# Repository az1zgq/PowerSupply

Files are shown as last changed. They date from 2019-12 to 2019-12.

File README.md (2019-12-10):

### Блок питания
Данный блок питания преобразует ~220В в 5В
#### Стукрура проекта
- [AD Libraries](AD%20Libraries)
    - [PCB Library Documents](AD%20Libraries/PCB%20Library%20Documents)
    - [Schematic Library Documents](AD%20Libraries/Schematic%20Library%20Documents)
- [Simulink](Simulink)
    - PowerSupply.ms14
- [Template](Template)
    - GOST 26.008-85.TTF
    - GOST 85.TTF
    - GOST type A.ttf
    - GOST type B.ttf
    - isocpeur-italic.ttf
    - isocpeur.ttf
- [pcbDrawing](pcbDrawing)
    - pcbDrawing.dwg
    - [pdfDrawing](pcbDrawing/pdfDrawing)
        - [ИУ4.11.03.03.19.05.02.04.001 Э1](pcbDrawing/pdfDrawing/%D0%98%D0%A34.11.03.03.19.05.02.04.001%20%D0%AD1.pdf)
        - [ИУ4.11.03.03.19.05.02.04.003 Э3](pcbDrawing/pdfDrawing/%D0%98%D0%A34.11.03.03.19.05.02.04.003%20%D0%AD3.pdf)
        - [ИУ4.11.03.03.19.05.02.04.003 ПЭ3](pcbDrawing/pdfDrawing/%D0%98%D0%A34.11.03.03.19.05.02.04.003%20%D0%9F%D0%AD3.pdf)
        - [ИУ4.11.03.03.19.05.02.04.004 ПП](pcbDrawing/pdfDrawing/%D0%98%D0%A34.11.03.03.19.05.02.04.004.pdf)
        - [ИУ4.11.03.03.19.05.02.04.005 СБ](pcbDrawing/pdfDrawing/%D0%98%D0%A34.11.03.03.19.05.02.04.005%20%D0%A1%D0%91.pdf)
        - [ИУ4.11.03.03.19.05.02.04.006 Э1с ](pcbDrawing/pdfDrawing/%D0%98%D0%A34.11.03.03.19.05.02.04.006.pdf)
        - [ИУ4.11.03.03.19.05.02.04.008 СП](pcbDrawing/pdfDrawing/%D0%98%D0%A34.11.03.03.19.05.02.04.008%20%D0%A1%D0%9F.pdf)
        - [experiment](pcbDrawing/pdfDrawing/experiment.pdf)
        - [RPZ](pcbDrawing/pdfDrawing/RPZ.pdf)

- [pcbBoard](pcbBoard)
    - powerSupply.PrjPcb
    - Schematic.SchDoc
    - pcbBoard.PcbDoc
    - pdf.OutJob
    - gerber.OutJob
    - [Корзина](pcbBoard/Корзина.pdf)

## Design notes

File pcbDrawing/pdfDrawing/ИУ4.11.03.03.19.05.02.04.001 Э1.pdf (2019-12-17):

Сетевое нааряжение 220 В 50 Гц | Выход 5 В Защита от короткого замыкания | Выпрямитель с фильтром | Силовые ключи | Импульсный трансформатор | Выходной выпрямитель на диоде шоттки | Блок индикации Схема стабилизации . Гальваническая развязка обратной связи по напряжению на оптроне | Разраб . Пров . Изм . Лист | № докум . | Подпись | Дата | Лит . | Масса | Масштаб Т .контр . | Лист | Листов 1 Реценз . Н .контр . Утв . | МГТУ им . Н .Э .Баумана Кафедра ИУ 4 Группа ИУ 4-52 Б Блок питания Схема электрическая структурная Исмаилов А .К . Сергеева М .Д . Семенцов С .Г . 1 Э | 4.11.03.03.19.05.04.001 | ИУ

Инв . № подл Подп . и Дата Взам .инв .№ Инв .№ дубл . Подп . и Дата Справ № Перв . примен . ИУ 4.11.03.03.19.02.04.001 Э 1 ИУ 4.11.03.03.19.05.02.04.001 Э 1 Схема управление ключом Копировал Формат А 3

ВЫПОЛНЕНО В СТУДЕНЧЕСКОЙ ВЕРСИИ ПРОГРАММЫ AUTODESK ВЫПОЛНЕНО В СТУДЕНЧЕСКОЙ ВЕРСИИ ПРОГРАММЫ AUTODESK

ВЫПОЛНЕНО В СТУДЕНЧЕСКОЙ ВЕРСИИ ПРОГРАММЫ AUTODESK ВЫПОЛНЕНО В СТУДЕНЧЕСКОЙ ВЕРСИИ ПРОГРАММЫ AUTODESK

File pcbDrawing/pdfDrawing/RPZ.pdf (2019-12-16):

Министерство науки и высшего образования Российской Федерации Федеральное государственное бюджетное образовательное учреждение высшего образования
«Московский государственный технический университет имени Н.Э. Баумана (национальный исследовательский университет МГТУ им. Н.Э. Баумана) »

ФАКУЛЬТЕТ Информатика и системы управления (ИУ)

КАФЕДРА Проектирование и технология производства электронной аппаратуры (ИУ4)

## РАСЧЕТНО-ПОЯСНИТЕЛЬНАЯ ЗАПИСКА

## К КУРСОВОЙ РАБОТЕ

## НА ТЕМУ: Разработка, моделирование и экспериментальное исследование Блока питания

Студент ___ИУ4-52____ | _______________________ Исмаилов А.К
(Группа) | (Подпись, дата)
Проверил: | _______________________ Сергеева М.Д
| (Подпись, дата)
Руководитель курсовой работы | _______________________ Семенцов С.Г
| (Подпись, дата)

2019 г.

АННОТАЦИЯ
Работа посвящена разработке Блока питания (в дальнейшем — изделия). В работе представлена схемотехническая часть, содержащая информацию об элементной базе и описание электрической принципиальной схемы. Работа представляет собой комплекс графических документов. Содержание графической части: схема электрическая принципиальная, чертеж печатной платы, сборочный чертеж, спецификации. В заключении представлены выводы о проделанной работе и соответствии разработанного устройства техническому заданию.
Ключевые слова: Блок питания, схемотехническое проектирование.

ABSTRACT

The work is devoted to the development of a power supply unit (hereinafter referred to as products).
The work presents the circuit parts in which there is information about the elementary base and a description of the electrical circuit diagrams. The work is a set of graphic documents. The contents of the graphic part: electrical schematic diagram, assembly diagram, specification. In conclusion, conclusions are presented about the work done and the compliance with the terms of reference developed by the device. Key words: power supply, circuit design.

СОДЕРЖАНИЕ

УСЛОВНЫЕ ОБОЗНАЧЕНИЯ, СОКРАЩЕНИЯ И ТЕРМИНЫ
1 СХЕМОТЕХНИЧЕСКОЕ ПРОЕКТИРОВАНИЕ ИЗДЕЛИЯ | 8
1.2 Анализ и разработка схемы электрической принципиальной (Э3) изделия | 9
Основные характеристики BD106 | 11
Транзистор ST13003 служит для усиления электрического тока и управления им | 11
Основные характеристики ST13003 | 11
Вывод: данный транзистор был выбран в виду своей доступности и простоты
использования | 11
Транзистор BD135 способен от небольшого входного сигнала управлять значительным
током в выходной цепи | 12
Основные характеристики BD135 | 12
Макс. напр. к-б при заданном обратном токе к и разомкнутой цепи эмиттера 45В | 12
Вывод: данный транзистор был выбран так как его описание подходит требованиям
технического задания | 12
Оптопара PC817B обеспечивает гальваническую развязку вторичных цепей блока
питания от напряжения сети | 12
Основные характеристики PC817B | 12
Вывод: данный элемент был выбран так как его характеристики удовлетворяют
требованиям технического задания | 12
Выводы | 13
2 КОНСТРУКТОРСКОЕ ПРОЕКТИРОВАНИЕ ИЗДЕЛИЯ | 14
2.1 Анализ и выбор конструкции и материала печатной платы изделия | 14
2.2 Анализ соединений КМО электронного модуля | 15
Выводы | 16
3 Моделирование устройства | 17
3.1 Компьютерное моделирование работы изделия | 17
ЗАКЛЮЧЕНИЕ | 22
СПИСОК ИСПОЛЬЗОВАННЫХ ИСТОЧНИКОВ | 23
1 СХЕМОТЕХНИЧЕСКОЕ ПРОЕКТИРОВАНИЕ ИЗДЕЛИЯ | 7
1.1 Анализ и разработка схемы электрической структурной (Э1) изделия | 7
1.2 Анализ и разработка схемы электрической принципиальной (Э3) изделия | 8

УСЛОВНЫЕ ОБОЗНАЧЕНИЯ, СОКРАЩЕНИЯ И ТЕРМИНЫ

ГОСТ | – Государственный стандарт;
ЕСКД | – Единая система конструкторской документации;
КМО | – Компонент монтируемый в отверстие;
ПП | – Печатная плата;
СТФ | – Стеклотекстолит фольгированный;
РПЗ | – Расчётно-пояснительная записка;
РТЗ | – Расширенное техническое задание;
РЭС | –Радиоэлектронные средства;
РЭА | – Радиоэлектронные аппаратура;
ТЗ | – Техническое задание;
ТЭЗ | – Типовой элемент замены;
ЭРЭ | – Электрорадиоэлементы;

ВВЕДЕНИЕ

Работа посвящена разработке Блока питания, изготовлению и экспериментальному исследованию
В работе представлена схемотехническая часть, содержащая информацию об элементной базе и описание электрической принципиальной схемы. Работа представляет собой комплекс графических документов
Целью работы является разработка макетного образца изделия, которое преобразует из сетевого переменного напряжения в постоянное, и проектирование сопровождаещего комплекта конструкторской документации. Для достижения поставленных целей в работе был решен следующий комплекс задач:
– разработка схемы электрической структурной изделия
– разработка схемы электрической принципиальной изделия;
– изготовления изделия;
– разработка топологии печатной платы устройства и создание соответствующих чертежей
– создание макетного образца устройства
– экспериментальное исследование устройства
Исходными данными для работы являются:
– задание на выполнение курсовой работы. Результатами работы являются:
– схема электрическая структурная изделия (Э1);
– схема электрическая принципиальная изделия (Э3);
– сравнение макетного образца с теоретическим исследованием (ПД1); – перечень элементов;
– чертеж печатной платы изделия;
– сборочный чертеж;
– разработанный экспериментальный макет изделия; – расчётно-пояснительная записка.

Структура и объём работы. Работа разделена на 4 главы.

В первой главе приведено схемотехническое проектирование изделия. В этой главе осуществляется разработка схемы электрической структурной и схемы электрической принципиальной изделия.

Во второй главе описывается разработанный для изделия алгоритм работы.

В третьей главе осуществляется разработка конструкции изделия. В главе проводится разработка конструкции, а также, последующие проверочные расчёты.

В четвёртой главе осуществляется исследование полученного макета изделия на работоспособность. В главе проводится разработка программы испытаний и осуществляется оценка результатов испытаний.

### 1 СХЕМОТЕХНИЧЕСКОЕ ПРОЕКТИРОВАНИЕ ИЗДЕЛИЯ

В главе представлены этапы схемотехнического проектирования изделия. Представлено описание принципа работы изделия, описание схемы электрической структурной (Э1), и схемы электрической принципиальной (Э3). Проведен выбор и обоснование элементной базы.

### 1.1 Анализ и разработка схемы электрической структурной (Э1)

изделия

Разработка схемы электрической структурной (Э1) изделия предполагает первоначальную оценку и выделение основных структурных частей, из которых состоит робот. Разработанная схема электрическая структурная (Э1)
изделия | представлена | на | рисунке | 1.1, | а | также | на | чертеже
ИУ4.11.03.03.19.05.02.04.001 Э1. Схема электрическая структурная (Э1) разработана согласно требованиям ГОСТ 2.702-75 [1] и включает в себя
следующие | функциональные | блоки: | ограничитель | пускового | тока,
выпрямитель с фильтром, силовые ключи, импульсный трансформатор, выходной выпрямитель на диоде шоттки, блок индикации, схема управление ключом, схема стабилизации.

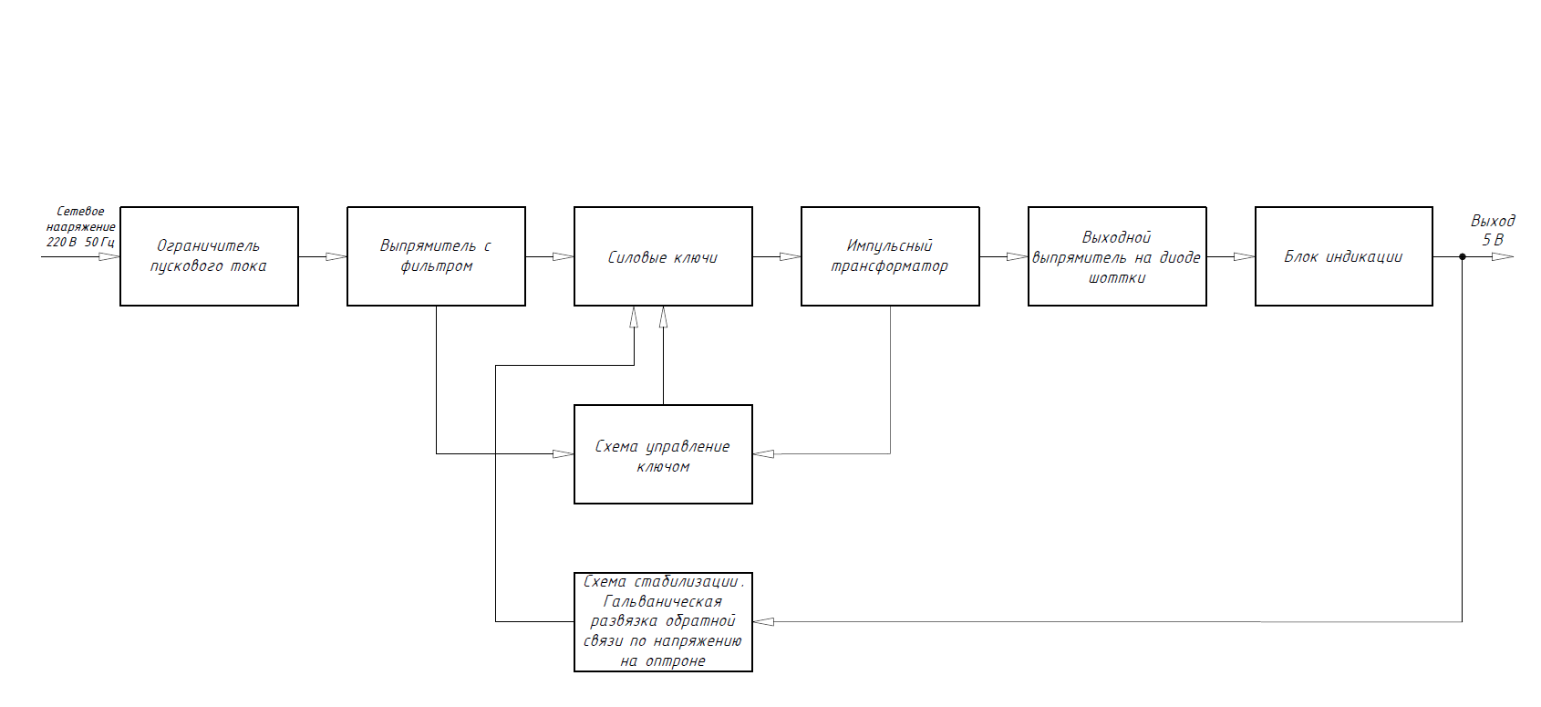
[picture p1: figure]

Рисунок 1.1 – Схема электрическая структурная (Э1) изделия Главным элементом схемы является трансформатор, он выполняет основные функции изделия: преобразовывает переменное напряжение и гальваническую развязку
Он служит для трансформации кратковременных импульсов напряжения, обычно периодически повторяющихся с высокой скважностью. (https://ru.wikipedia.org/wiki/%D0%A1%D0%BA%D0%B2%D0%B0%D0%B6%D0%BD%D0%BE%D1%81%D1%82%D1%8C)
В результате анализа схемы электрической структурной (Э1), представленной на рисунке 1.1, было получено общее представление о составных частях разрабатываемого изделия.

### 1.2 Анализ и разработка схемы электрической принципиальной (Э3)

изделия

Схема электрическая принципиальная (Э3) изделия была разработана согласно требованиям ГОСТ 2.701-84[2], ГОСТ 2.702-75 [1] , ГОСТ 2.708-81 [3] , ГОСТ 2.728-74 [4] , ГОСТ 2.730-73 [5] , ГОСТ 2.743-91 [6] , ГОСТ 2.759-82
[7] . Схема электрическая принципиальная (Э3) изделия изображена на чертеже: ИУ4.11.03.03.19.05.02.04.003 Э3, также данный чертёж представлен на рисунке 1.2.

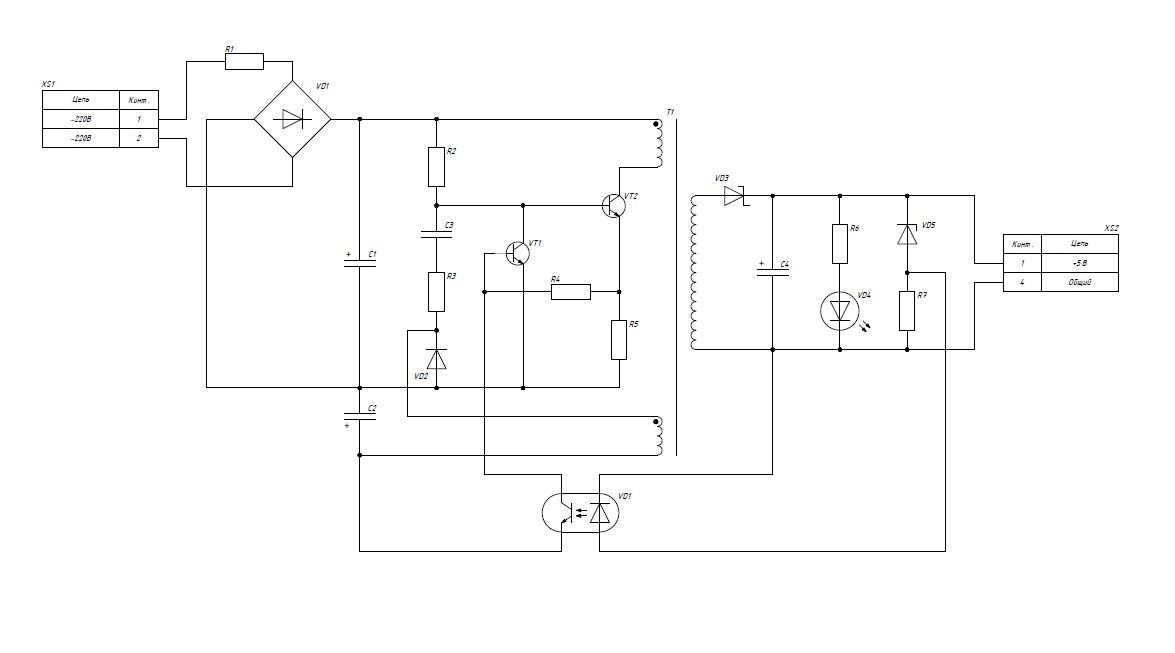
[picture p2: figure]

Рисунок 1.2 – Схема электрическая принципиальная (Э3) блока управления

Диодный мост DB106, в изделии предназначен для преобразования переменного тока в пульсирующий.

Основные характеристики BD106
Максимальное постоянное обратное напряжение 800B Максимальное импульсное обратное напряжение 960В Максимальный прямой ток 1А
Максимальный допустимый прямой импульсный ток 30А Максимальный обратный ток 10мкА
Максимальное прямое напряжение 1.1В
Рабочая температура -55…+125С

Вывод: данный диодный мост был выбран так как его характеристики удовлетворяют требованиям технического задания.

Транзистор ST13003 служит для усиления электрического тока и управления им.

Основные характеристики ST13003

Макс. напр. к-б при заданном обратном токе к и разомкнутой цепи эмиттера 700В
Макс. напр. к-э при заданном токе к и разомкнутой цепи б 400В Максимально допустимый ток коллектора 1.5А
Максимальная рассеиваемая мощность 40Вт

Вывод: данный транзистор был выбран в виду своей доступности и простоты использования.

Транзистор BD135 способен от небольшого входного сигнала управлять значительным током в выходной цепи

Основные характеристики BD135

Макс. напр. к-б при заданном обратном токе к и разомкнутой цепи эмиттера 45В

Макс. напр. к-э при заданном токе к и разомкнутой цепи базы 45 Максимально допустимый ток коллектора 1.5А
Максимальная рассеиваемая мощность 8Вт

Вывод: данный транзистор был выбран так как его описание подходит требованиям технического задания.

Оптопара PC817B обеспечивает гальваническую развязку вторичных цепей блока питания от напряжения сети.

Основные характеристики PC817B
Напряжение изоляции 5кВ
Максимальный прямой ток 50мА Максимальное выходное напряжение 70В
Напряжение коллектор-эмиттер 35 В
Ток коллектора 50 мА

Вывод: данный элемент был выбран так как его характеристики удовлетворяют требованиям технического задания.

Выводы

В главе проведено схемотехническое проектирование изделия. Была разработана схема электрическая структурная (Э1) изделия, в которой были выделены основные структурные узлы изделия.
Заключительным этапом схемотехнического проектирования стала разработка схемы электрической принципиальной (Э3) изделия, в которой подробно описаны соединения всех ЭРЭ изделия и благодаря условным графическим обозначениям однозначно определяется функционал каждого ЭРЭ. Данные схемы представлены на чертежах ИУ4.11.03.03.19.05.02.04.003 Э3, а также на рисунках 1.1.

### 2 КОНСТРУКТОРСКОЕ ПРОЕКТИРОВАНИЕ ИЗДЕЛИЯ

В главе представлены этапы конструкторского проектирования изделия. Проведена компоновка блоков изделия. Разработана печатная плата изделия и проведено моделирование устройства, подтверждающие работоспособность разработанной конструкции изделия.

### 2.1 Анализ и выбор конструкции и материала печатной платы

изделия

Печатная Плата изделия представляет собой одностороннюю ПП. Разработанный чертеж печатной платы изделия представлена на рисунке 2.1, а также на чертеже ИУ4.11.03.03.19.05.02.04.004 ПП

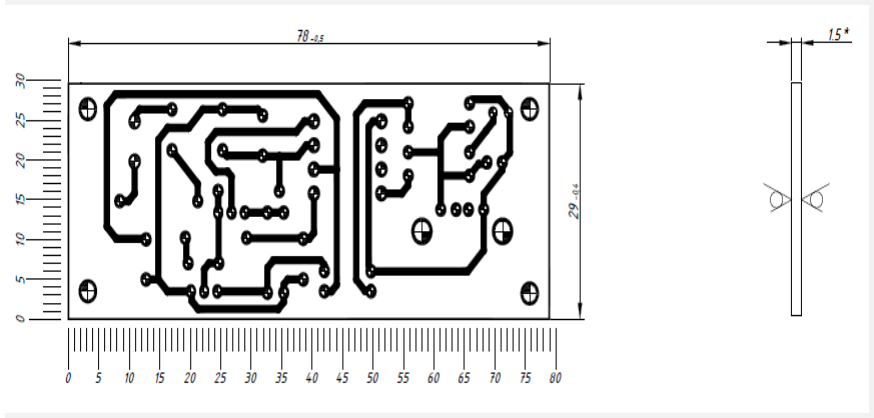
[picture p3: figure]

Рисунок 2.1 – Чертеж печатной платы

### 2.2 Анализ соединений соединений КМО электронного модуля

Для установки КМО на ПП использовался припой ПОС-61 ГОСТ 21930-
76. Пайка производилась паяльником. Разработанный сборочный чертеж (СБ)
изделия | представлен | на | рисунке | 2.2, | а | также | на | чертеже
ИУ4.11.03.03.19.05.02.04.005СП

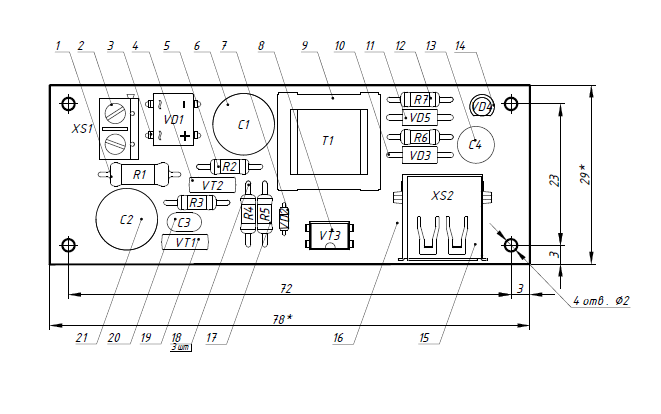
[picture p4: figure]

Рисунок 2.2 – Сборочный чертеж электронного модуля

Выводы

В данном разделе была проанализирована компоновка изделия.
В результате анализа ПП изделия была выбрана конструкция ПП, расположение печатных проводников ПП, а также материал изготовления ПП. В результате анализа электрических соединений был выбран припой для установки КМО на ПП.

### 3 Моделирование устройства

3.1 Компьютерное моделирование работы изделия.

Моделирование работы устройства было проведено в программном пакете Multisim. Рабочее поле программы с моделью Изделия представлено на (Рис. 3.1).
В ходе моделирования была подтверждена работоспособность схемы, а так же подтверждены заявленные в техническом задании входные и выходные параметры: входное напряжение 220В 50Гц, выходное напряжение 5В, максимальная выходная мощность 3,5Вт. На основе полученных данных было принято решение о целесообразности изготовления этого изделия.

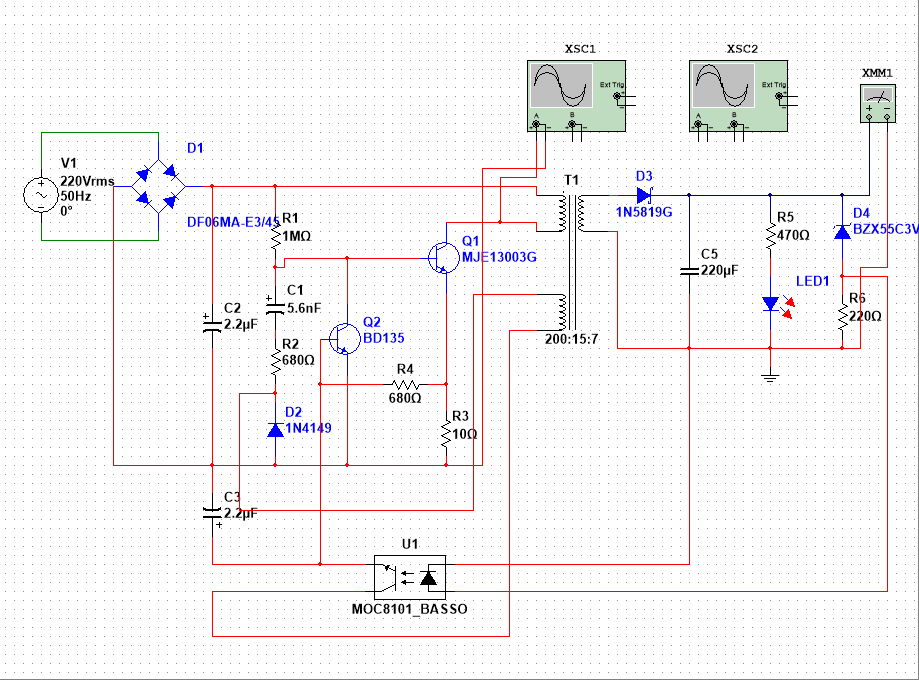
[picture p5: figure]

Рисунок 3.1 – Компьютерное моделирование работы изделия

В результате на компьютерной модели изделия были замерены потребляемые сила тока и напряжения, представленные на рисунке 3.2. Сила тока составила 0,3А, а напряжение 4,97 В. Перемножив эти значения мы можем вычислить потребляемую мощность, равную 1,491 Вт.

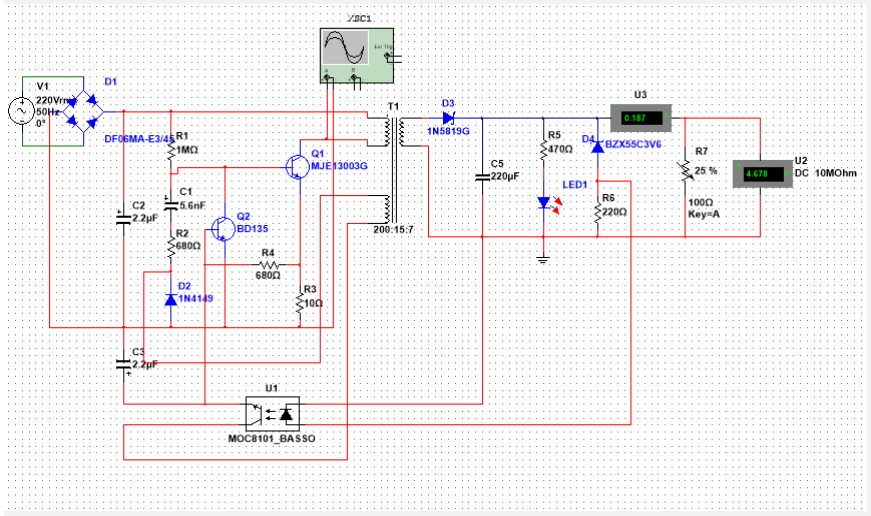
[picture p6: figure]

Рисунок 3.2 – Измерение максимального выходного тока Блок питания стремится на выходе поддерживать постоянное напряжение равное 5В. При уменьшении сопротивления увеличивается выходной ток, но блок питания не может выдать бесконечно большой ток и это число ограниченно характеристиками блока питания. При сопротивлении меньше 20 напряжение на выходе начинает падать, это связанно с тем что ток на выходе перестал увеличиваться.
Cхема обладает стабилизацией выходного напряжения и способна выдавать ток до 0.5 А. На самом деле блок может выдавать и больше, но при повышении тока на выходе начинает срабатывать защита от перегрузки и выходное напряжение начинает уменьшаться. Защита от перегрузок и КЗ реализована на резисторе 10 ом в цепи эмиттера силового транзистора и маломощном транзисторе BD135. При повышении тока через первичную обмотку трансформатора на эмиттерном резисторе создается падение напряжения, достаточное для открытия BD135, который в свою очередь притягивает базу силового транзистора к минусу, тем самым закрывая его и уменьшая длительность импульсов через первичную обмотку. При изменении номинала данного резистора можно увеличить или уменьшить ток срабатывания защиты.
Сильно увеличивать тоже не надо, так как это повлечет за собой повышение нагрева силового транзистора и увеличит вероятность выхода последнего из строя. Стабилизация выполнена на распространенном оптроне pc817 и на стабилитроне 3.9 В (при изменении номинала которого можно менять выходное напряжение). При превышении выходного напряжения, светодиод оптрона начинает светиться ярче, вызывая повышение тока через транзистор оптрона на базу BD135 и, как следствие, закрытие силового ключа. При уменьшении выходного напряжения, наоборот, транзистор оптрона начнет закрываться и BD135 не будет обрывать импульсы на базе силового ключа, тем самым увеличивая их длительность и, соответственно, увеличение выходного напряжения.
Особое внимание стоит уделить намотке трансформатора. Поскольку блок однотактный, потребуется трансформатор с немагнитным зазором между половинками сердечника. Зазор нужен для быстрого размагничивания сердечника и для предотвращения вхождения феррита в на насыщение. Расчет трансформатора надо проводить в специальных программах, что в таких маломощных блоках питания первичная обмотка состоит из 190-220 витков провода 0.08-0.1мм. Чем больше сердечник, тем меньше витков. Поверх первичной в том же направлении мотается базовая обмотка. Она состоит из 7 – 15 витков того же провода. И в конце уже более толстым проводом мотается вторичная обмотка. Число витков 5-7. Крайне важно мотать все обмотки в одном направлении и помнить, где начало и конец. На схеме точками указаны начала обмоток.
Данный блок можно применять там, где не нужен высокий ток, а нужна компактность, например для питания микросхем или для зарядки устройств с аккумуляторами небольшой ёмкости. Из плюсов данного блока питания можно отметить компактность, наличие защиты и стабилизации и, конечно, простоту

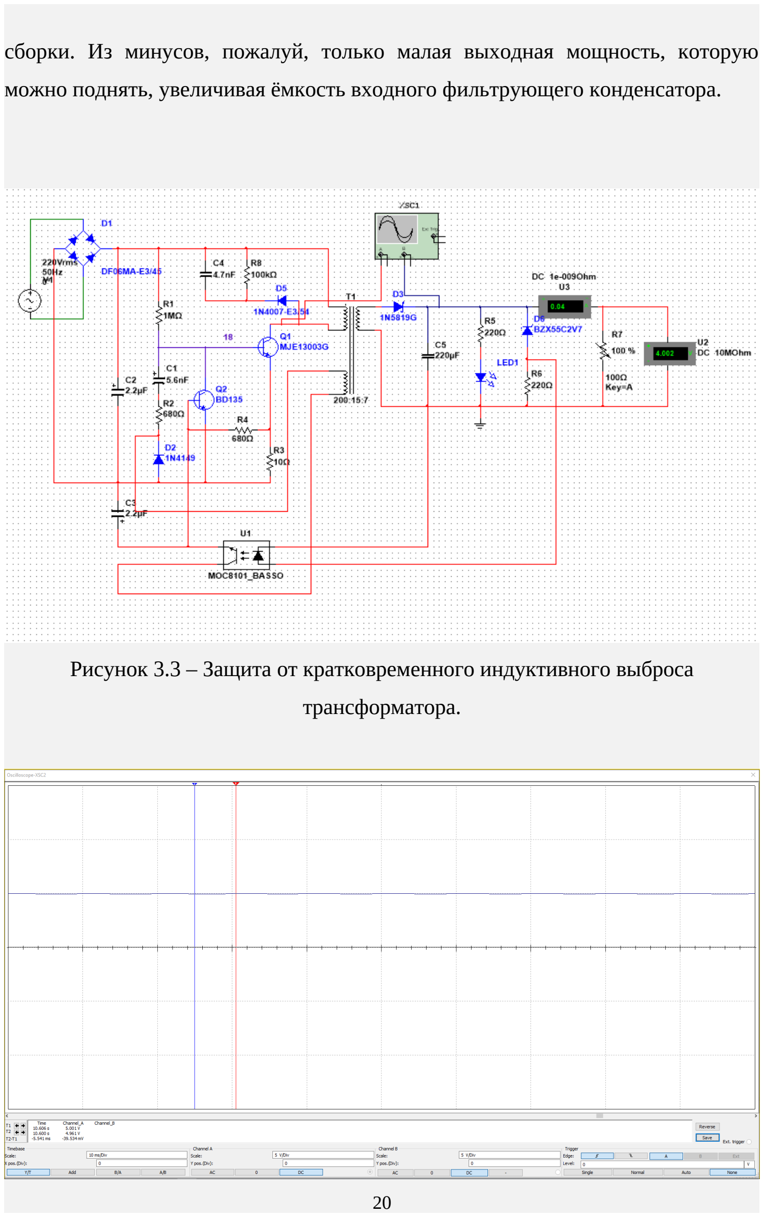
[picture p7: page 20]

сборки. Из минусов, пожалуй, только малая выходная мощность, которую можно поднять, увеличивая ёмкость входного фильтрующего конденсатора.

Рисунок 3.3 – Защита от кратковременного индуктивного выброса трансформатора.

Рисунок 3.4 – Осциллограмма выходного напряжения

Выводы
В результате была получена стабильная система управления изделия. Выполнено моделирование схемы изделия в программе Multisim. Работа модели и потребляемая мощность практически полностью соответствует техническому заданию.

ЗАКЛЮЧЕНИЕ

Был проведен анализ РТЗ на проектирование изделия. Были выявлены основные требования к разрабатываемому изделию, его режимам работы, условиям эксплуатации и хранения.
Проведен обзор аналога разрабатываемого изделия. По результатам анализа и сопоставления технических характеристик и стоимостей была обоснована целесообразность разработки и изделия с характеристиками, указанными в РТЗ.
Проведено схемотехническое проектирование изделия. Была разработана схема электрическая структурная (Э1) изделия, в которой были выделены
основные | структурные | узлы | изделия. | Заключительным | этапом
схемотехнического проектирования стала разработка схемы электрической принципиальной (Э3) изделия, в которой подробно описаны соединения всех ЭРЭ изделия и благодаря условным графическим обозначениям однозначно определяется функционал каждого ЭРЭ.
Проведена разработка алгоритма работы.
В результате анализа электронного модуля изделия, были выбраны конструкция ПП, расположение слоёв печатных проводников ПП, а также материал изготовления ПП.
В результате анализа электрических соединений были выбраны припой и паяльная паста для установки КМО и КМП, соответственно, на ПП.
Опытный образец изделия успешно прошёл испытания на измерительном стенде, а выходной сигнал изделия соответствует требованиям, указанным в техническом задании.
В итоге проделанной работы можно сделать вывод, что разработанное изделие соответствует требованиям технического задания.

СПИСОК ИСПОЛЬЗОВАННЫХ ИСТОЧНИКОВ

1. ГОСТ 2.702-75 «Правила выполнения электрических схем».
2. ГОСТ 2.701-84 «Схемы. Виды и типы. Общие требования к выполнению».
3. ГОСТ 2.708-81 «Правила выполнения электрических схем цифровой вычислительной техники».
4. ГОСТ 2.728-74 «Обозначения условные графические в схемах. Резисторы, конденсаторы».
5. ГОСТ 2.730-73 «Приборы полупроводниковые».
6. ГОСТ 2.743-91 «Элементы цифровой техники».
7. ГОСТ 2.759-82 «Элементы аналоговой техники».
8. ГОСТ 19.701-90 «Схемы алгоритмов, программ, данных и систем. Обозначения условные и правила выполнения».
9. Проектирование конструкций радиоэлектронной аппаратуры: Учеб. Пособие для вузов/ Е.М. Парфёнов, Э.Н. Камышная, В.П. Усачёв. – М.: Радио и связь, 1989. – 272 с.: ил.
10. Конструкторско-технологические проектирование электронной аппаратуры: Учебник для вузов / К.И. Билибин, А.И, Власов, Л.В. Журавлева и др. Под общ.ред. В.А. Шахнова – М.: Изд-во МГТУ им. Н.Э. Баумана, 2002.
11. Ким Д.П. Теория автоматического управления. Том 1. Линейные системы, М.: Физматлит, 2003. — 288 с
12. Ким Д.П. Теория автоматического управления. Том 2. Нелинейные системы, М.: Физматлит, 2004. -464 с
13. Современные системы управления, Р. Дорф, Р. Бишоп. Пер. с англ. Б. И. Копылова. – М.: Лаборатория базовых знаний, 2002. – 832 стр.

ПРИЛОЖЕНИЕ А

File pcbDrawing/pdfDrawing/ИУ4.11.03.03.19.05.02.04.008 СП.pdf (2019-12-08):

Инв . № подл Подп . и Дата Взам .инв .№ Инв .№ дубл . Подп . и Дата Справ № Перв . примен . Изм . Лист № докум . Лит . Листов

1 МГТУ им . Н .Э .Баумана Кафедра ИУ

4 Группа ИУ 4-52

Б Лист Блок питания перечень элементов Подпись Дата Разраб . Пров . Реценз . Н .контр . Утв . | Исмаилов А .К . Сергеева М .Д . Семенцов С .Г . | ИУ 4.11.03.03.19.05.02.04.008

1

2 Копировал | Формат A4

Форм . Зона

## Поз .Обозначение Наименование

Кол . Примечание Детали ИУ 4.11.03.03.19.05.02.04.004 Печатная плата Документация A3 ИУ 4.11.03.03.19.05.02.04.005 СБ Сборочный чертеж

ИУ 4.11.03.03.19.05.02.04.001 | 1 A3

Э

ИУ 4.11.03.03.19.05.02.04.003 1 | Схема электрическая структурная A1 | 1

Э

ИУ 4.11.03.03.19.05.02.04.003 ПЭ 3 | Схема электрическая принципиальная A4
ИУ 4.11.03.03.19.05.02.04.006 ИУ 4.11.03.03.19.05.02.04.001 3 | Перечень элементов A3 Чертеж печатной платы | 1 A1 1

Э

1 | Измерительный стенд
| В 1N4148, Диод 150 мА 100 | 1
31110 | В DB106, Диодный мост 1A 800 В | 1
| 1 А 40 | 1 VD3 VD1 VD2 Конденсаторы ECAP
К 50-35 - 2.2 мкФ ,400 В ECAP | 1
К 50-35 - 10 мкФ ,400 В | 1 C1C2C3C4 1
К 10-17 Б - 56 пФ ,50B ECAP | 1

К 50-35 - 220 мкФ ,10 В

6212013 | структурная
| | 1 Схема электрическая ИУ 4.11.03.03.19.05.02.04.007 ПД
1 | Плакат демонстрационный
| 1N5819, Диод Шоттки | 1 Прочие изделия Диоды 16 1 A3 A3
| | 1

ВЫПОЛНЕНО В СТУДЕНЧЕСКОЙ ВЕРСИИ ПРОГРАММЫ AUTODESK ВЫПОЛНЕНО В СТУДЕНЧЕСКОЙ ВЕРСИИ ПРОГРАММЫ AUTODESK

ВЫПОЛНЕНО В СТУДЕНЧЕСКОЙ ВЕРСИИ ПРОГРАММЫ AUTODESK ВЫПОЛНЕНО В СТУДЕНЧЕСКОЙ ВЕРСИИ ПРОГРАММЫ AUTODESK

Инв . № подл Подп . и Дата Взам .инв .№ Инв .№ дубл . Подп . и Дата Справ № Перв . примен . Изм . Лист № докум . Подпись Дата Лист

2 ИУ 4.11.03.03.19.05.02.04.008 Копировал | Формат A4

Форм . Зона

## Поз .Обозначение Наименование

Кол . Примечание PC817B, Оптопара с Оптопары транзисторным выходом

1 VT3

С 2-23 - 2 Вт - 1 Ом ± 5% Резисторы

| 1
С 1-4 - 0.25 Вт - 1 МОм ±5% | R3,R4,R6 R5R7 R1R2 1
С 2-23 - 0.25 Вт - 680 Ом ±1% | 1
С 2-23 - 0.25 Вт - 10 Ом ±1% | 1 VT2 1

В тип A угловая С 1-4 - 0.25 Вт - 220 Ом ±5%

| 1 BD135, 45, 1 Светодиоды Стабилитроны 1
В ,5% | VD4VD5
| 1 T1 GNL-3012HD, красный 1N4730A, 3.9
В , 1.5A, 12.5 Вт ST13003, 400 | 1 VT1
А , 40 Вт Транзисторы Трансформаторы FWPTEE16H812K85 85-265 В , 1.5 | 1

) Клеммник винтовой , 306-021-12 2- контактный , 5 мм, прямой

1 Разъемы USBA-1J (DS1095 B-R), XS2 XS1

8

2 15

| ( черная

15171812 14 194 12 11

ВЫПОЛНЕНО В СТУДЕНЧЕСКОЙ ВЕРСИИ ПРОГРАММЫ AUTODESK ВЫПОЛНЕНО В СТУДЕНЧЕСКОЙ ВЕРСИИ ПРОГРАММЫ AUTODESK

ВЫПОЛНЕНО В СТУДЕНЧЕСКОЙ ВЕРСИИ ПРОГРАММЫ AUTODESK ВЫПОЛНЕНО В СТУДЕНЧЕСКОЙ ВЕРСИИ ПРОГРАММЫ AUTODESK

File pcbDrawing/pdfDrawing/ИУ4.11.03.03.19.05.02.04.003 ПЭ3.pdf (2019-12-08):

Инв . № подл Подп . и Дата Взам .инв .№ Инв .№ дубл . Подп . и Дата Справ № Перв . примен . Изм . Лист № докум .

Зона Поз . Обозна
-чение | Обозначение

# Кол .Примечание Лит . Листов

1 МГТУ им . Н .Э .Баумана Кафедра ИУ

4 Группа ИУ 4-52

Б Лист Блок питания перечень элементов Подпись Дата Разраб . Пров . Реценз . Н .контр . Утв . | Исмаилов А .К . Сергеева М .Д . Семенцов С .Г . | ИУ 4.11.03.03.19.05.02.04.003 ПЭ

3

1

2 GNL-3012HD, Светодиод красный 60° 700 нМ (Red) 1N4730A, Стабилитрон 3.9

В , 5%, 1 Вт , [DO-41]

С 2-23 - 0.25 Вт - 10 Ом ±1%, ОЖО .567.081 ТУ

С 2-23 - 0.25 Вт - 680 Ом ±1% ОЖО .567.081 ТУ

С 1-4 - 0.25 Вт - 220 Ом ±5%, ОЖО .567.081 ТУ FWPTEE16H812K 85-265

В , 50-60 Гц , 8.1 мГн VD4VD5 R3,R4,R6 R5R7 T1

1

1

3

1

1 Светодиоды Стабилитроны R1

С 2-23 - 2 Вт - 1 Ом ± 5% ОЖО .467.081 ТУ

1 Резисторы Конденсаторы ECAP

К 50-35 - 2.2 мкФ ±10%-400

В Y5V ECAP

К 50-35 - 10 мкФ ±10%-400 В Y5V

К 10-17

Б - 56 пФ ±5%-50B NPO ECAP

К 50-35 - 220 мкФ ±10%-10 В Y5V C1C2C3C4

1

1

1

1 R2

С 1-4 - 0.25 Вт - 1 МОм ±5% ОЖО .467.081 ТУ

1

1 Трансформаторы VD3 1N5819, Диод Шоттки

1 А 40 В [DO-41]

1 VD1 | DB106, Диодный мост 1A 800 В [DB-1]
1 Диоды VD2 | 1N4148, Диод 150 мА 100 В [DO-35]
1 Копировал | Формат A4

ВЫПОЛНЕНО В СТУДЕНЧЕСКОЙ ВЕРСИИ ПРОГРАММЫ AUTODESK ВЫПОЛНЕНО В СТУДЕНЧЕСКОЙ ВЕРСИИ ПРОГРАММЫ AUTODESK

ВЫПОЛНЕНО В СТУДЕНЧЕСКОЙ ВЕРСИИ ПРОГРАММЫ AUTODESK ВЫПОЛНЕНО В СТУДЕНЧЕСКОЙ ВЕРСИИ ПРОГРАММЫ AUTODESK

Инв . № подл Подп . и Дата Взам .инв .№ Инв .№ дубл . Подп . и Дата Справ № Перв . примен . Зона Поз . Обозна
-чение | Обозначение

Кол .Примечание Изм . Лист № докум . Подпись Дата Лист

## 2 ИУ 4.11.03.03.19.05.02.04.003 ПЭ

3 BD135, Транзистор NPN 45 В 1.5A 12.5 Вт [SOT-32] ST13003, Транзистор NPN 400 В 1.5 А 40 Вт [TO-126] PC817B, Оптопара с транзисторным выходом [DIP-4] VT2VT3 | Транзисторы VT1

1 Оптопары

1 тип A угловая

( черная

)

1 XS1 Клеммник винтовой , 306-021-12, 2- контактный

5 мм, прямой

1 Разъемы XS2 | USBA-1J (DS1095 B-R), Розетка на плату , Копировал | Формат A4

1

ВЫПОЛНЕНО В СТУДЕНЧЕСКОЙ ВЕРСИИ ПРОГРАММЫ AUTODESK ВЫПОЛНЕНО В СТУДЕНЧЕСКОЙ ВЕРСИИ ПРОГРАММЫ AUTODESK

ВЫПОЛНЕНО В СТУДЕНЧЕСКОЙ ВЕРСИИ ПРОГРАММЫ AUTODESK ВЫПОЛНЕНО В СТУДЕНЧЕСКОЙ ВЕРСИИ ПРОГРАММЫ AUTODESK

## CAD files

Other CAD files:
pcbDrawing/pcbDoc.dwg

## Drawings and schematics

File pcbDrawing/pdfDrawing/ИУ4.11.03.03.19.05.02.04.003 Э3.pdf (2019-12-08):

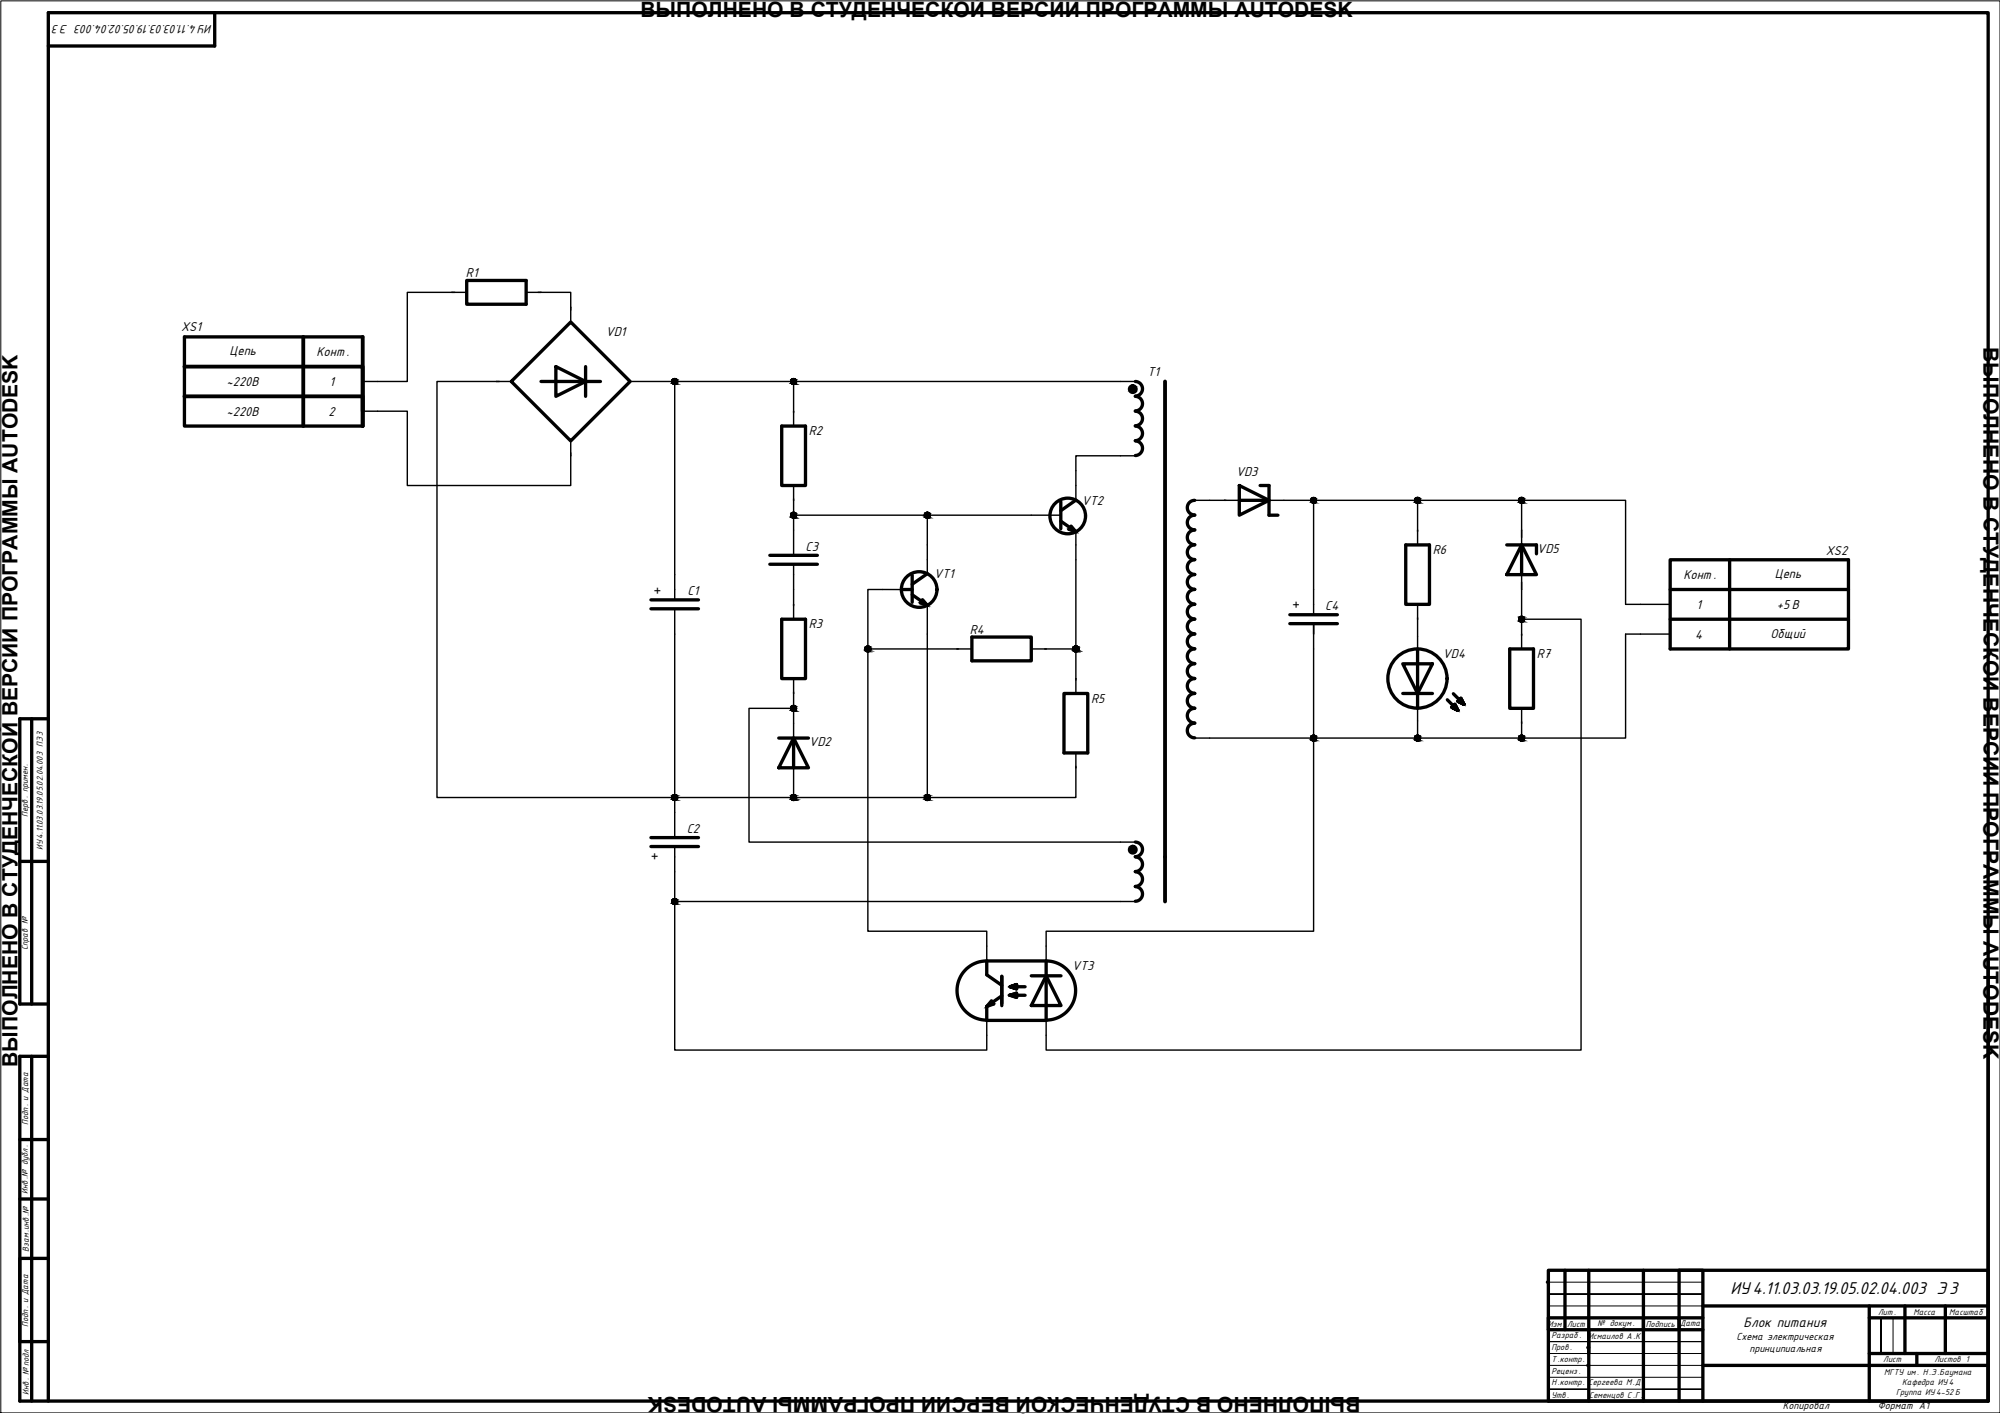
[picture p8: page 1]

ВЫПОЛНЕНО В СТУДЕНЧЕСКОЙ ВЕРСИИ ПРОГРАММЫ AUTODESK

Цепь

C4 Инв . № подл Подп . и Дата Взам .инв .№ Инв .№ дубл . Подп . и Дата Справ

4 | Общий

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

Схема электрическая принципиальная | | Группа ИУ 4-52 Б Блок питания

МГТУ им . Н .Э .Баумана Кафедра ИУ 4

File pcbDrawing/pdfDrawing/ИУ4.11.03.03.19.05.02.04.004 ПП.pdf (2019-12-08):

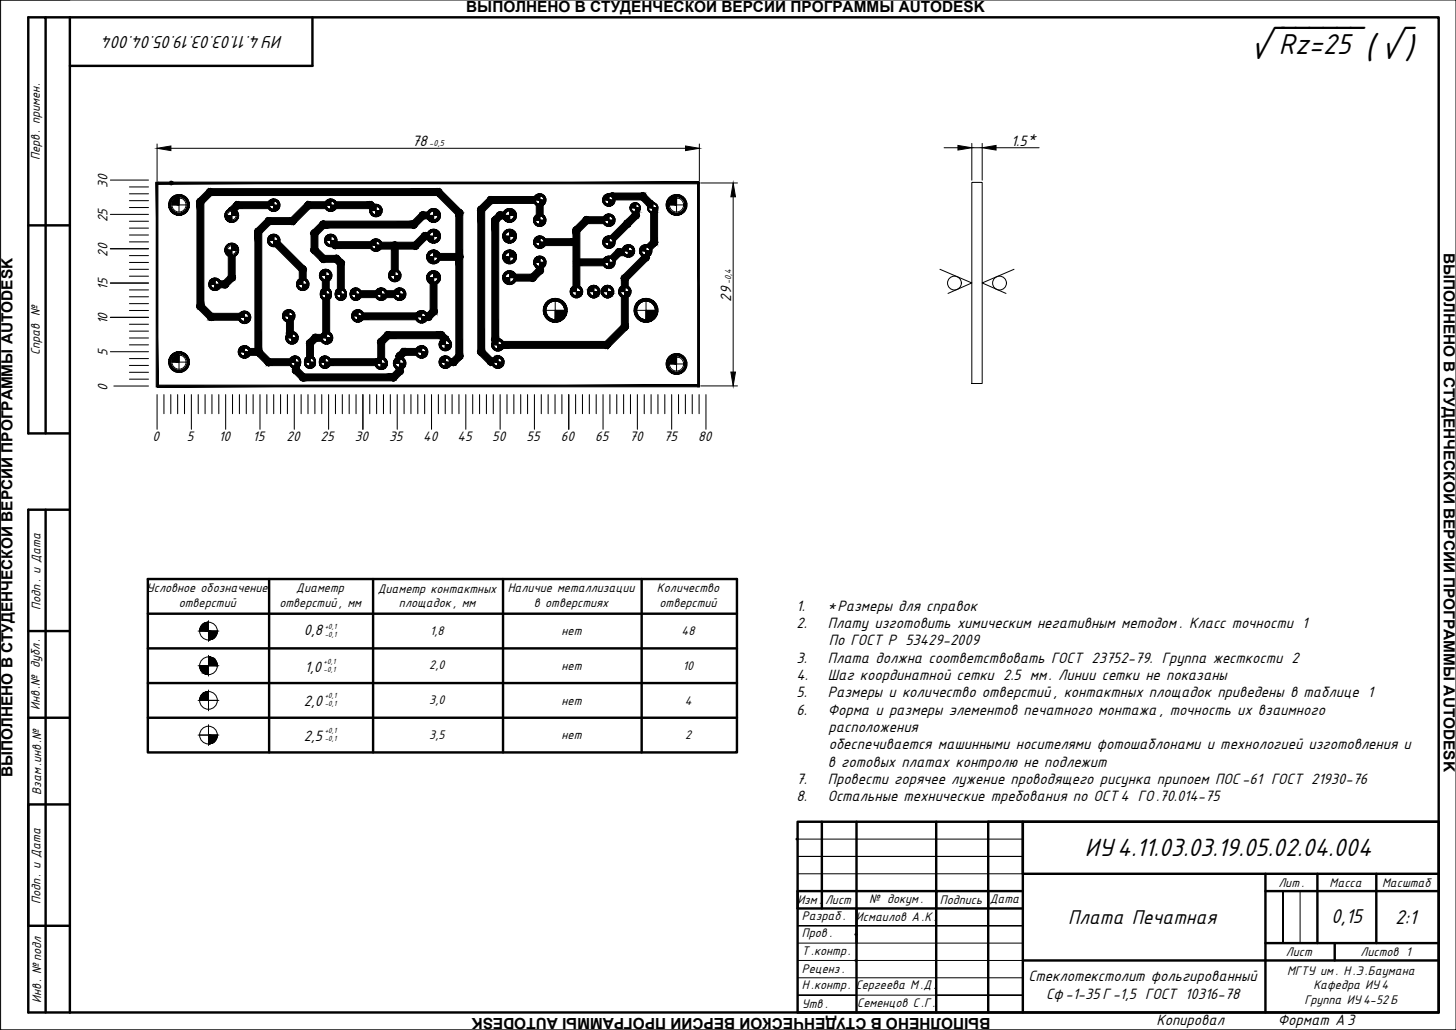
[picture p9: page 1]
Разраб . Пров . Изм . Лист; № докум .; Подпись; Дата; Реценз . Н .контр . Утв .; МГТУ им . Н .Э .Баумана; Кафедра ИУ 4 Группа ИУ 4-52 Б; № Перв . примен .; отверстий; *Размеры для справок; Стеклотекстолит фольгированный Сф -1-35 Г -1,5 ГОСТ 10316-78; Копировал; Формат А 3

ВЫПОЛНЕНО В СТУДЕНЧЕСКОЙ ВЕРСИИ ПРОГРАММЫ AUTODESK

Условное обозначение отверстий | Диаметр отверстий , мм | Диаметр контактных площадок , мм | Наличие металлизации в отверстиях | Количество

2. Плату изготовить химическим негативным методом . Класс точности 1 По ГОСТ Р 53429-2009

0,8 +0,1 -0,1 | 1,8 | нет | 48

+0,1 1,0 -0,1 | 2,0 | нет | 10

3. Плата должна соответствовать ГОСТ 23752-79. Группа жесткости 2
4. Шаг координатной сетки 2.5 мм. Линии сетки не показаны
5. Размеры и количество отверстий , контактных площадок приведены в таблице 1
6. Форма и размеры элементов печатного монтажа , точность их взаимного
расположения
обеспечивается машинными носителями фотошаблонами и технологией изготовления и
в готовых платах контролю не подлежит
7. Провести горячее лужение проводящего рисунка припоем ПОС -61 ГОСТ 21930-76
8. Остальные технические требования по ОСТ 4 ГО .70.014-75

+0,1 2,0 -0,1 | 3,0 | нет | 4

+0,1 2,5 -0,1 | 3,5 | нет

Плата Печатная | Лит . | Масса | Масштаб

Т .контр . | Исмаилов А .К . Сергеева М .Д . Семенцов С .Г . | | | Лист | Листов 1

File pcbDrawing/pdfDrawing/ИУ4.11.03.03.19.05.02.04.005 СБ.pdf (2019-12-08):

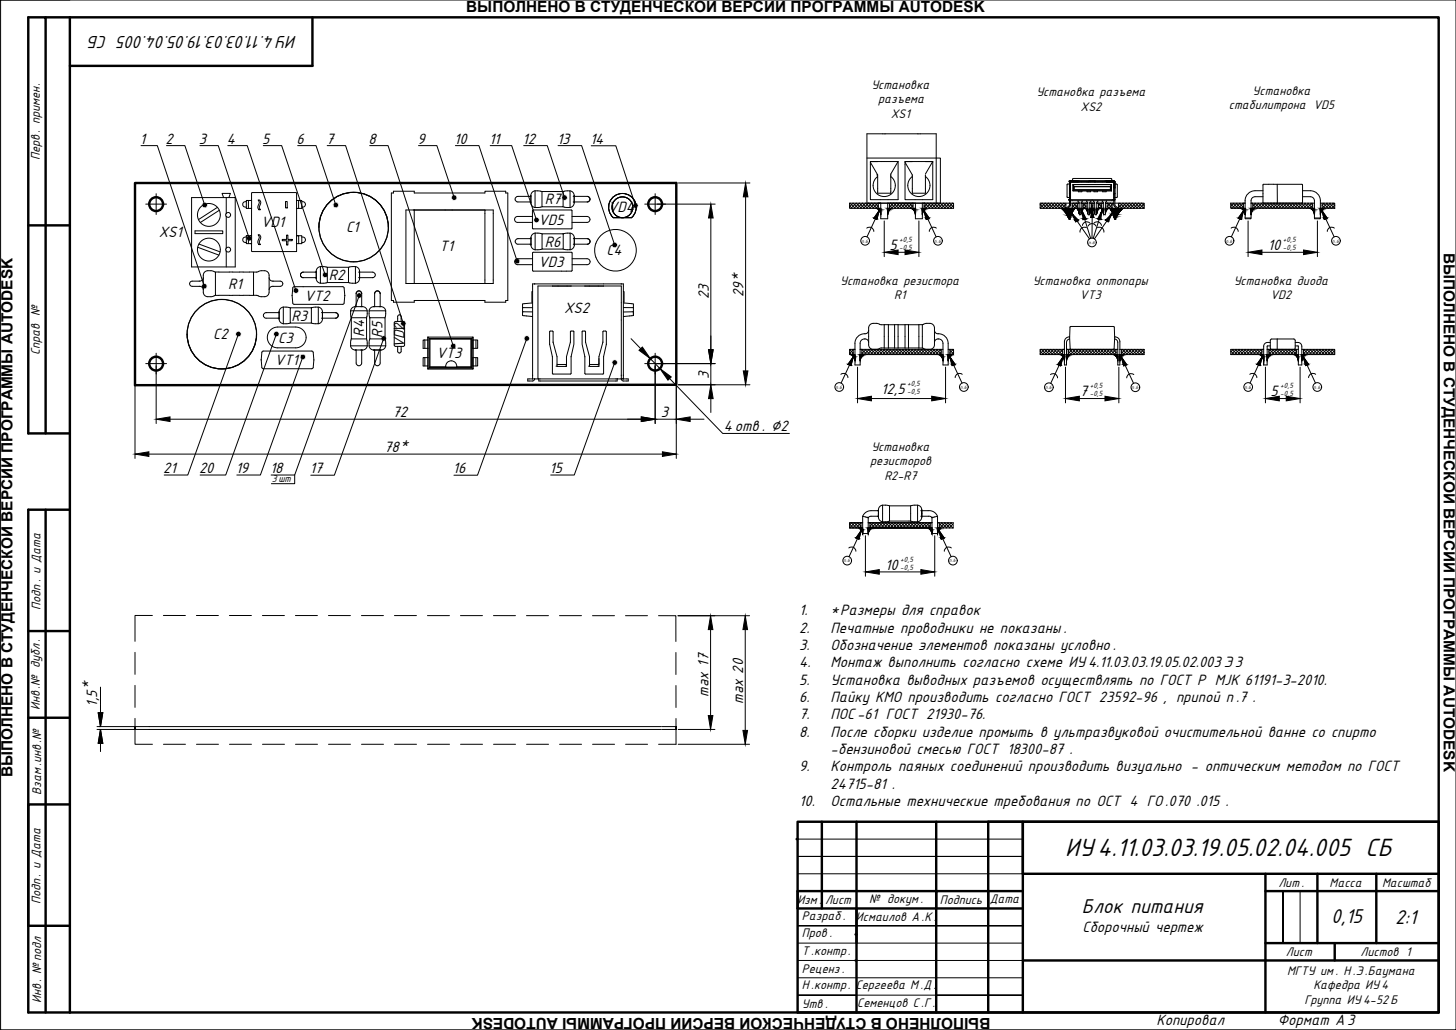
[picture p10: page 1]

ВЫПОЛНЕНО В СТУДЕНЧЕСКОЙ ВЕРСИИ ПРОГРАММЫ AUTODESK

5. Установка выводных разъемов осуществлять по ГОСТ Р MJK 61191-3-2010.
6. Пайку КМО производить согласно ГОСТ 23592-96 , припой п .7 .
7. ПОС -61 ГОСТ 21930-76.
8. После сборки изделие промыть в ультразвуковой очистительной ванне со спирто
-бензиновой смесью ГОСТ 18300-87 .
9. Контроль паяных соединений производить визуально - оптическим методом по ГОСТ
10. Остальные технические требования по ОСТ 4 ГО .070 .015 .

Блок питания Сборочный чертеж | Лит . | Масса | Масштаб

Т .контр . | Исмаилов А .К . Сергеева М .Д . Семенцов С .Г . | | | Лист | Листов 1

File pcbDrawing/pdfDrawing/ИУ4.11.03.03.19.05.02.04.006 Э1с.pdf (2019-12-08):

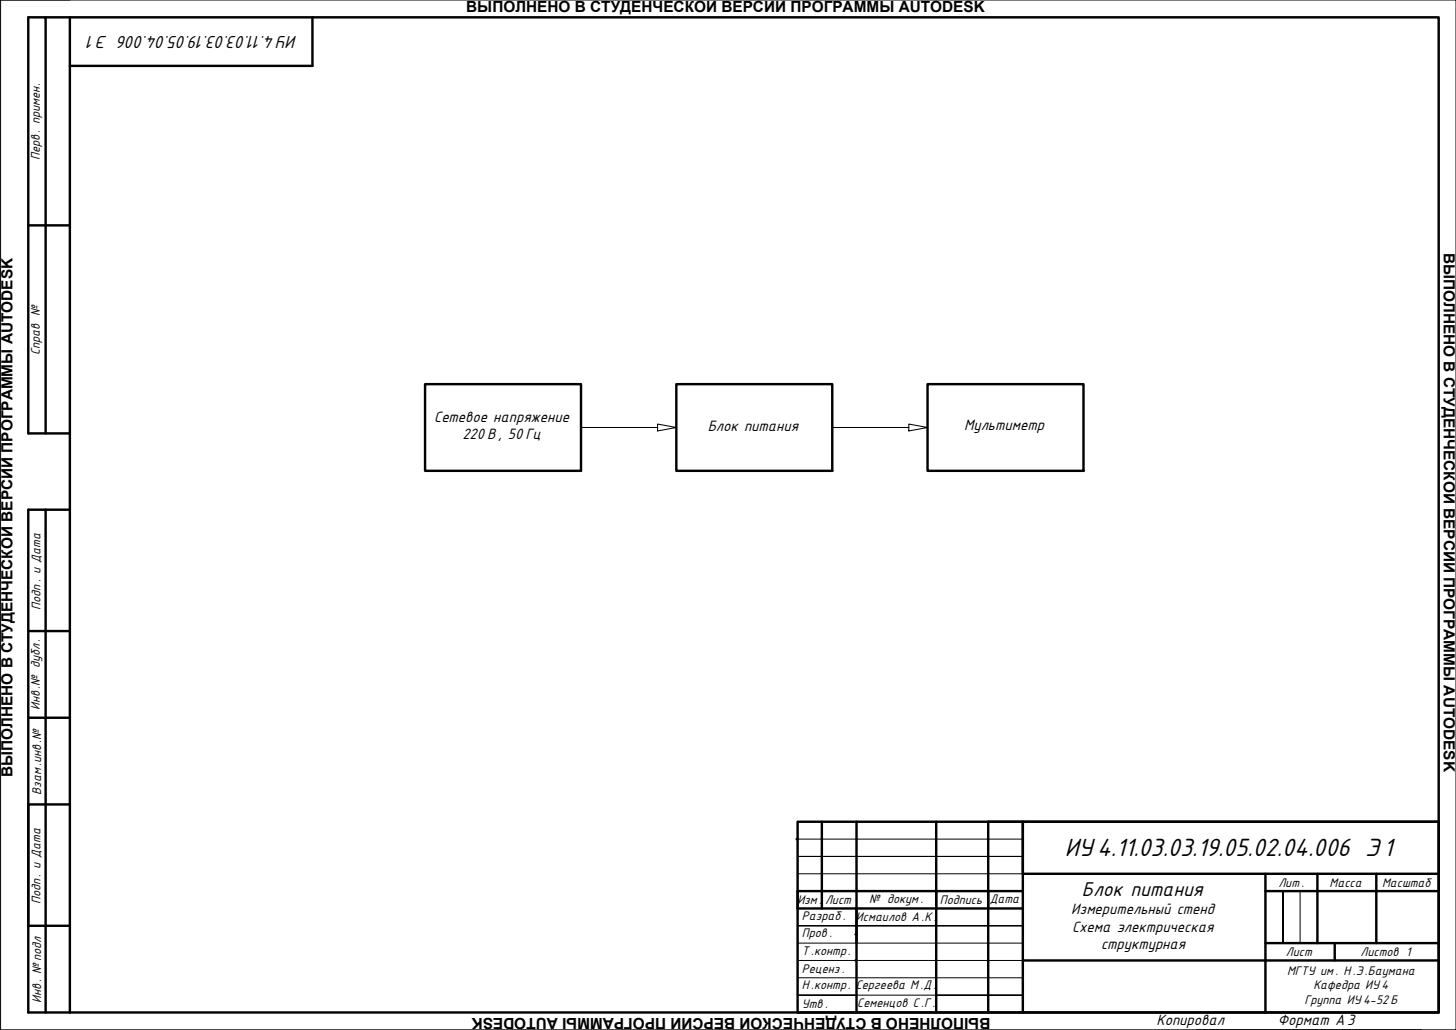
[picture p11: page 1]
Разраб . Пров . Изм . Лист; № докум .; Подпись; Дата; Т .контр .; Лист; Листов 1; Реценз . Н .контр . Утв .; МГТУ им . Н .Э .Баумана; Кафедра ИУ 4 Группа ИУ 4-52 Б; № Перв . примен .; Блок питания; Копировал; Формат А 3; Сетевое напряжение 220 В , 50 Гц

ВЫПОЛНЕНО В СТУДЕНЧЕСКОЙ ВЕРСИИ ПРОГРАММЫ AUTODESK

Блок питания Измерительный стенд Схема электрическая структурная | Лит . | Масса | Масштаб

Исмаилов А .К . Сергеева М .Д . Семенцов С .Г .

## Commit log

2019-09-29 deleted 3d components
    [ALSRobot-TO-92A.step, CAPACITOR 10uF.STEP, CAPACITOR 220.STEP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]
2019-09-29 Create Корзина 1
2019-10-04 update pcb lib
    [Devices.PcbLib, Devices.SchLib, Power.PrjPcb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]
2019-10-05 updated devices
    [Devices.PcbLib, Devices.SchLib, Schematic.SchDoc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]
2019-10-06 updated devices & sch.lib
    [Devices.PcbLib, Devices.SchLib, Schematic.SchDoc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]
2019-10-06 23 30
    [pcbBoard.PcbDoc]
2019-10-07 07.10.19 (22:51)
    [Schematic.SchDoc, pcbBoard.PcbDoc]
2019-10-09 09.10.19 (22.17)
    [pcbBoard.PcbDoc]
